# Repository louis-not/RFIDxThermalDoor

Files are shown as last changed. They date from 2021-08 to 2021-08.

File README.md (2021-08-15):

# RFIDxThermalDoor
[Indonesia]
Alat Pengunci Pintu Contactless berbasis RFID dan Sensor Suhu Infrared didesain dengan mempertimbangkan kondisi pandemi yang bertujuan untuk mengurangi kontak gagang pintu dengan tangan pengguna. Alat ini dapat digunakan dengan mengintegrasikan dengan sistem pengunci pintu konvensional atau sebagai mekanisme penguncian pintu atau digunakan sebagai stand-alone device.

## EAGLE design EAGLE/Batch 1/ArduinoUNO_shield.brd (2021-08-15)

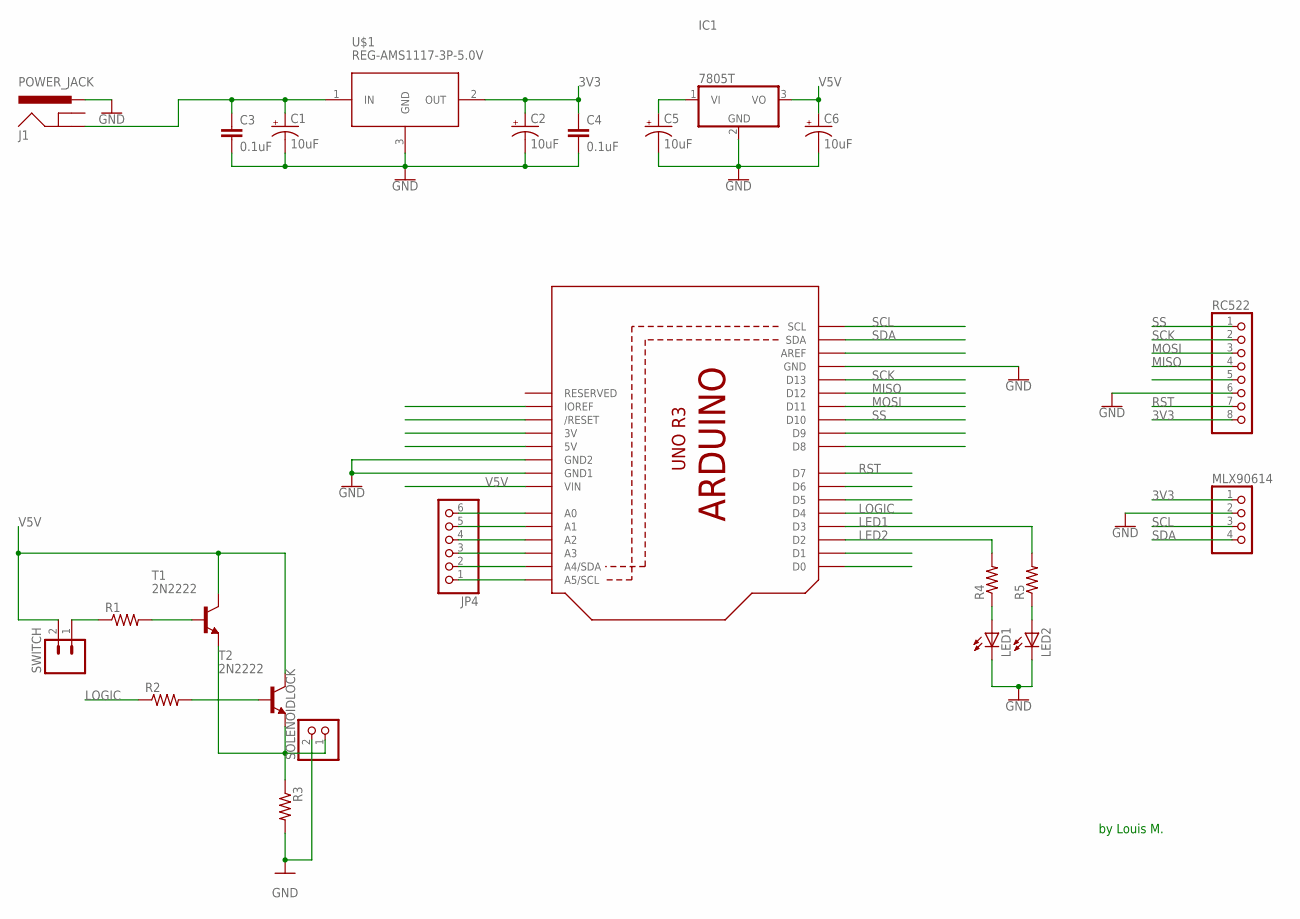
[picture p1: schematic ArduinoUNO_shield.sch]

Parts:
C1, C2: 10uF; CPOL-RADIAL-2.5MM-5MM-KIT
C3, C4: 0.1uF; CAP-PTH-SMALL-KIT
C5, C6: 10uF; CPOL-RADIAL-2.5MM-5MM
IC1: 7805T; TO220H
J1: POWER_JACK; POWER_JACK_PTH
JP4: PINHD-1X6B; 1X06-BIG
LED1, LED2: LED5MM
MLX90614: PINHD-1X4; 1X04
R1, R2, R3: R-US_0207/10; 0207/10
R4, R5: R-US_0204/5; 0204/5
RC522: PINHD-1X8; 1X08
SOLENOIDLOCK: JST_2PIN-THM-RA; JST-PH-2-THM-RA
SWITCH: M02; 02P
T1, T2: 2N2222; TO92-EBC-OVAL
U$1: REG-AMS1117-3P-5.0V; REG-AMS1117-3P
UNOR3: ARDUINOR3-DIMENSION; ARDUINOR3

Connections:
3V3: C2.1 (+), C4.1, MLX90614.1, RC522.8, U$1.2 (OUT)
GND: C1.2 (-), C2.2 (-), C3.2, C4.2, C5.2 (-), C6.2 (-), IC1.2 (GND), J1.PWR, LED1.K (C), LED2.K (C), MLX90614.2, R3.2, RC522.6, SOLENOIDLOCK.2 (1), U$1.3 (GND), UNOR3.GND, UNOR3.GND1, UNOR3.GND2
LED1: R5.2, UNOR3.D3
LED2: R4.2, UNOR3.D2
LOGIC: R2.1, UNOR3.D4
MISO: RC522.4, UNOR3.D12
MOSI: RC522.3, UNOR3.D11
unnamed: R1.2, T1.B
unnamed: R1.1, SWITCH.1
unnamed: R2.2, T2.B
unnamed: LED1.A, R4.1
unnamed: R3.1, SOLENOIDLOCK.1 (2), T1.E, T2.E
unnamed: LED2.A, R5.1
unnamed: C5.1 (+), IC1.1 (VI)
unnamed: C1.1 (+), C3.1, J1.GND, U$1.1 (IN)
unnamed: JP4.6, UNOR3.A0
unnamed: JP4.5, UNOR3.A1
unnamed: JP4.4, UNOR3.A2
unnamed: JP4.3, UNOR3.A3
unnamed: JP4.2, UNOR3.A4 (A4/SDA)
unnamed: JP4.1, UNOR3.A5 (A5/SCL)
RST: RC522.7, UNOR3.D7
SCK: RC522.2, UNOR3.D13
SCL: MLX90614.3, UNOR3.SCL
SDA: MLX90614.4, UNOR3.SDA
SS: RC522.1, UNOR3.D10
V5V: C6.1 (+), IC1.3 (VO), SWITCH.2, T1.C, T2.C, UNOR3.VIN

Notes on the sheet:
by Louis M.

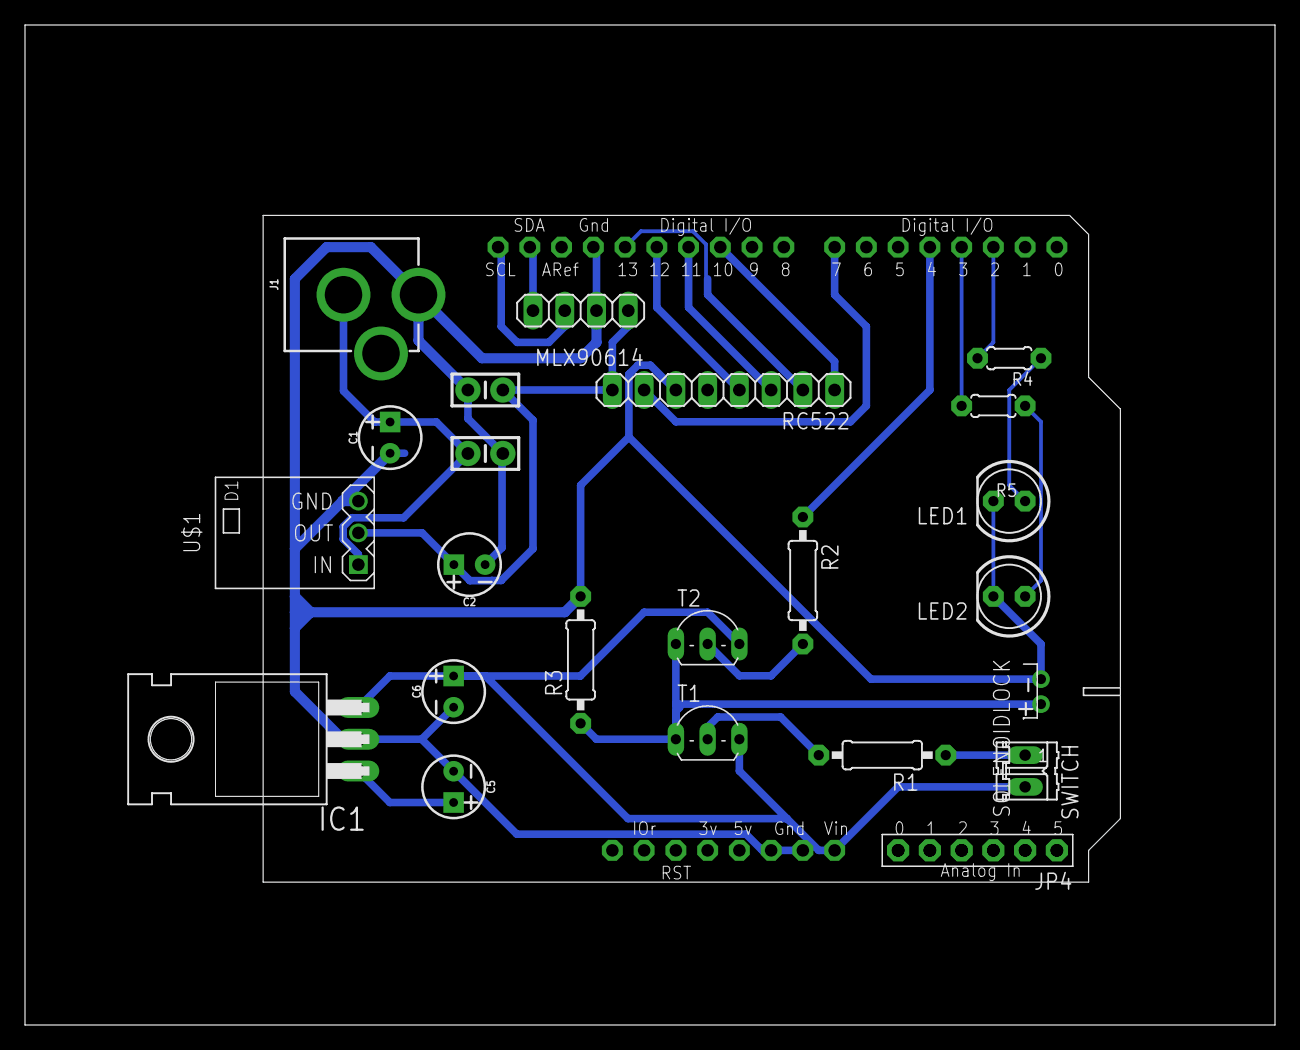
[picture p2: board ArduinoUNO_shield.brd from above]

Board: 2 copper layers, 100.0 x 80.0 mm, 24 parts (0 on the bottom side), 27 nets.

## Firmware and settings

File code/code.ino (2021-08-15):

#include <SPI.h>  // RFID
#include <MFRC522.h> // RFID Sensor
#include <Wire.h> // I2C, for Thermometre
#include <avr/wdt.h> // Watchdog timer
#include <Adafruit_MLX90614.h> // thermometer
#define SS_PIN 10 // RFID
#define RST_PIN 7 // RFID
#define LOGIC 4
#define LED1 2 // Red
#define LED2 3 // Blue


MFRC522 mfrc522(SS_PIN, RST_PIN); 
Adafruit_MLX90614 mlx = Adafruit_MLX90614();

void setup() {
  Serial.begin(57600) ;
  SPI.begin();
  
  // RFID Setup
  mfrc522.PCD_Init() ;
  Serial.println("Setup 1");

  // RELAY Setup
  pinMode(LOGIC, OUTPUT) ;
  Serial.println("Setup 2");
  
  // Temperature Setup
  const int constant = 1.5 ;// kalibrasi thermometer terhadap jarak pengukuran 5 cm
  mlx.begin();
  Serial.println("Setup 3");
  
  // Indicator Setup
  pinMode(LED1, OUTPUT) ;
  pinMode(LED2, OUTPUT) ;
  Serial.println("Setup 4");
  
  // Watchdog timer setup 
//  wdt_enable(WDTO_8S) ;
  Serial.println("Setup 5");
  
  // Success Setup
  for (int i = 0; i < 3 ; i++ ){
    digitalWrite(LED1, HIGH);
    delay(500) ;
    digitalWrite(LED1, LOW) ;  
  }
  Serial.println("Setup Success");
}

void loop() {
  wdt_reset() ;
//  Serial.println("Begin test") ;
  if ( ! mfrc522.PICC_IsNewCardPresent()) 
  {
    return;
  }
  // Select one of the cards
  if ( ! mfrc522.PICC_ReadCardSerial()) 
  {
    return;
  }
  Serial.println("pass") ;
  String userID = "";
  byte letter ;
  for (byte i = 0; i < mfrc522.uid.size; i++){
     Serial.print(mfrc522.uid.uidByte[i] < 0x10 ? " 0" : " ");
     Serial.print(mfrc522.uid.uidByte[i], HEX);
     userID.concat(String(mfrc522.uid.uidByte[i] < 0x10 ? " 0" : " "));
     userID.concat(String(mfrc522.uid.uidByte[i], HEX));
  }
  wdt_reset() ;
  Serial.println();
  userID.toUpperCase();
  if (userID.substring(1) == "02 AC 7E D1 E1 0E B0" || userID.substring(1) == "E5 AD 8D 4F") {
    digitalWrite(LED1, HIGH) ;
    Tempcheck() ;   
    delay(2000) ;
  } else {
    delay(2000) ;
  }

  //reset indicator
  digitalWrite(LED1, LOW);
  digitalWrite(LED2, LOW);
  Serial.println("reset complete") ;
  delay(2000);
}

void Tempcheck(){
  wdt_reset() ;
  while (1){
    float temp = mlx.readObjectTempC() ;
    if (temp > 34 && temp < 40) {
      Serial.println(temp) ;
      if (temp >= 37 ){
        digitalWrite(LED1, LOW) ;
        Serial.println("GO AWAY");
        } else {
        Serial.println("GET IN!") ;
        digitalWrite(LED2, HIGH) ;
        digitalWrite(LOGIC, HIGH) ;
        delay (5000) ;
        digitalWrite(LOGIC, LOW) ;
        }
        wdt_reset() ;
        break ;
//      Serial.println("Breaking out");
    } else {
      wdt_reset() ;
      continue ; 
    }
  }


}

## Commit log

2021-08-15 Add files via upload
    add git
    [ArduinoUNO_shield.brd, ArduinoUNO_shield.sch]
2021-08-15 add PCB board

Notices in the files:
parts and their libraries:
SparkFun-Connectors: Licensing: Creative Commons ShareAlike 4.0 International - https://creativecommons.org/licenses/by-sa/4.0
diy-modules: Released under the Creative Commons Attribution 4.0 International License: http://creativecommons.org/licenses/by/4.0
